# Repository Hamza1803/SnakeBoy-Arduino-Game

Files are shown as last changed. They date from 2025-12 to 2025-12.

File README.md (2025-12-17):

# 🐍 SnakeBoy – An Arduino-Powered Snake Game Console



A handheld, retro-inspired Snake game console built with Arduino and open-source hardware. SnakeBoy combines embedded programming, hardware optimization, and mechanical design into an accessible and highly optimized gaming device.

**Developed as part of the Creative Electronics course in the Electronics Engineering program at the University of Málaga.**

---

## 📋 Overview

SnakeBoy is a handheld console featuring the classic Snake game displayed on a 32×8 LED matrix. Built around an Arduino Leonardo-compatible board (Save Maker I), this project demonstrates practical embedded systems design with real-time gameplay, persistent high score storage, and optimized resource utilization.

### 🎯 Design Goals
- Demonstrate embedded programming and hardware optimization techniques
- Create a fully functional gaming device using accessible components
- Utilize open-source tools and methodologies
- Achieve minimal resource footprint (<15 KB Flash, ~2. 5 KB RAM)

---

## 🕹️ Key Features

- **Real-time Gameplay**:  Responsive joystick and directional button controls
- **Audio Feedback**: 6 distinct melodies via PWM buzzer
- **Persistent Storage**:  High scores saved in EEPROM memory
- **Efficient Architecture**: State-machine-driven game logic with zero blocking delays
- **Compact Footprint**: <15 KB Flash / ~2.5 KB RAM usage — highly optimized
- **Custom Graphics**: 7×5 pixel font and smooth menu animations
- **Custom Enclosure**: 3D-printed case with precision-engineered component cutouts
- **Status Indicator**: Visual feedback LED for game states
- **USB Powered**: Connected operation via 5V/1A USB power supply

---

## 📦 Hardware Specifications

### Core Components

| Component | Specification |
|---|---|
| **Microcontroller** | Save Maker I (Arduino Leonardo-compatible) |
| **Display** | 4× cascaded MAX7219 8×8 LED matrices (32×8 total resolution) |
| **Input:  Analog** | PS4-style analog joystick with integrated L3 push button |
| **Input: Digital** | 4× tactile push buttons (Up, Down, Left, Right) |
| **Audio Output** | Passive buzzer with PWM modulation |
| **Visual Indicator** | Red 5mm status LED |
| **Power Supply** | External 5V/1A USB power supply (wired connection) |

### Important Notes
⚠️ **LED Matrix Power**:  The LED matrix **must be powered externally via 5V** with a **shared ground connection** to prevent flickering and signal instability.

---

## 🔧 Pinout Configuration

| Component | Arduino Pin | Function |
|---|---|---|
| MAX7219 Data | D13 | Serial data input |
| MAX7219 Clock | D11 | Clock signal |
| MAX7219 Load | D10 | Latch/load signal |
| Buzzer | D12 | PWM audio output |
| Status LED | D7 | Visual state indicator |
| Joystick X-Axis | A0 | Analog X input |
| Joystick Y-Axis | A1 | Analog Y input |
| Joystick Button (L3) | D9 | Push button input |
| Up Button | D8 | Directional input |
| Down Button | D4 | Directional input |
| Left Button | D5 | Directional input |
| Right Button | D6 | Directional input |

**Note**: All digital buttons utilize the internal `INPUT_PULLUP` feature, eliminating the need for external pull-up resistors.

---

## 📁 Repository Structure

```
SnakeBoy-Arduino-Game/
├── arduino/
│   └── main/
│   │   ├── snake. cpp           # Main game logic and state machine
│   │   ├── display.cpp         # LED matrix driver and rendering
│   │   ├── inputs.cpp          # Joystick and button input handling
│   │   ├── sound.cpp           # Audio synthesis and melody management
│   │   ├── led. cpp             # Status LED control
│   │   └── config.h            # Hardware configuration and pin mappings
│   └── test/
│   │   └── test_display.txt
│   │   └── test_input.txt
│   │   └── test_led_buzzer.txt
├── 3D printer/
│   ├── case/               # OpenSCAD 3D models (parametric design)
│   │   ├── front_panel.scad
│   │   ├── back_panel.scad
│   │   └── button. scad
│   │   └── button. scad
│   │   └── button. scad
├── diagrams/           # Wiring and schematic diagrams
├── README.md               # This file
└── LICENSE                 # CC BY-NC-SA 4.0 License
```

---

## 🛠️ Getting Started

### Prerequisites
- Arduino IDE 1.8.0 or later
- Arduino Leonardo board or compatible (Save Maker I)
- MAX7219 LED matrix module (32×8)
- Joystick and push buttons
- Buzzer and status LED
- 5V/1A USB power supply

### Installation

1. **Clone the repository**
   ```bash
   git clone https://github.com/Hamza1803/SnakeBoy-Arduino-Game. git
   ```

2. **Install dependencies**
   - Download the `LedControl` library in Arduino IDE:  `Sketch → Include Library → Manage Libraries` → Search "LedControl"
   - Download the `MD_MAX72XX` library in Arduino IDE:  `Sketch → Include Library → Manage Libraries` → Search "MD_MAX72XX"

3. **Configure hardware**
   - Review `config.h` and verify pin mappings match your setup
   - Ensure external 5V power is connected to the LED matrix

4. **Upload firmware**
   - Connect your Arduino Leonardo board via USB
   - Open `snake.cpp` in Arduino IDE
   - Select Board: Arduino Leonardo
   - Click Upload

5. **Connect power**
   - Connect the 5V/1A USB power supply to the designated connector
   - The device should power on automatically

---

## 🎮 Gameplay Instructions

- **Move**: Use joystick or directional buttons (Up, Down, Left, Right)
- **Start Game**: Press any button or move joystick
- **Pause**: Press L3 button (joystick button)
- **Game Over**:  Collision with wall or self triggers game over
- **High Score**:  Automatically saved to EEPROM

---

## 👥 Contributors

**Project Team**:  
- **Hamza Lotfi** 
- **Andreea Simion** 

**Educational Institution**: 
Degree in Electronic Systems Engineering
University of Málaga, School of Telecommunications

---

## 📖 Additional Resources

- **Full Tutorial**: [SnakeBoy – An Arduino-Powered Snake Game Console](https://www.instructables.com/SnakeBoy-an-Arduino-Powered-Snake-Game-Console/) on Instructables
- **MAX7219 Datasheet**: Available from component suppliers
- **Video Full Game** : https://youtu.be/4og9s7oPVPE
---

## ⚖️ License

This project is licensed under the **Creative Commons Attribution-NonCommercial-ShareAlike 4.0 International (CC BY-NC-SA 4.0)** license.

**You are free to**:
- Share and adapt the material
- Use for educational purposes

**Under the terms that you**:
- Provide attribution to the original creators
- Do not use commercially
- Share derivative works under the same license

For complete license details, see the [LICENSE](./LICENSE) file or visit [creativecommons.org](https://creativecommons.org/licenses/by-nc-sa/4.0/).

---

## 🐛 Troubleshooting

### LED Matrix not displaying
- Verify external 5V power is connected with shared ground
- Check MAX7219 pin connections (DATA, CLK, LOAD)
- Test with the LedControl example sketch

### Joystick not responding
- Calibrate analog input in `inputs.cpp`
- Verify A0 and A1 connections
- Check for loose wiring

### Sound not working
- Verify buzzer polarity and D12 connection
- Check that `sound.cpp` is compiled

---

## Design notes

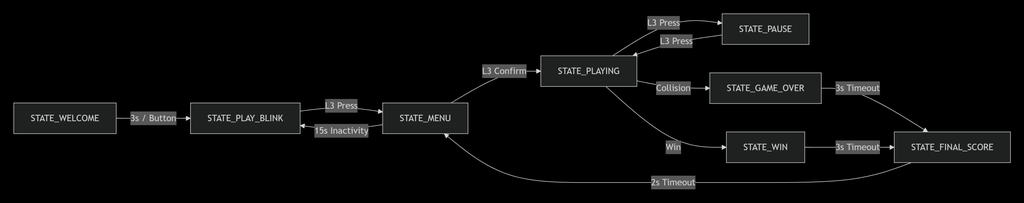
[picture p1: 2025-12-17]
diagrams.webp

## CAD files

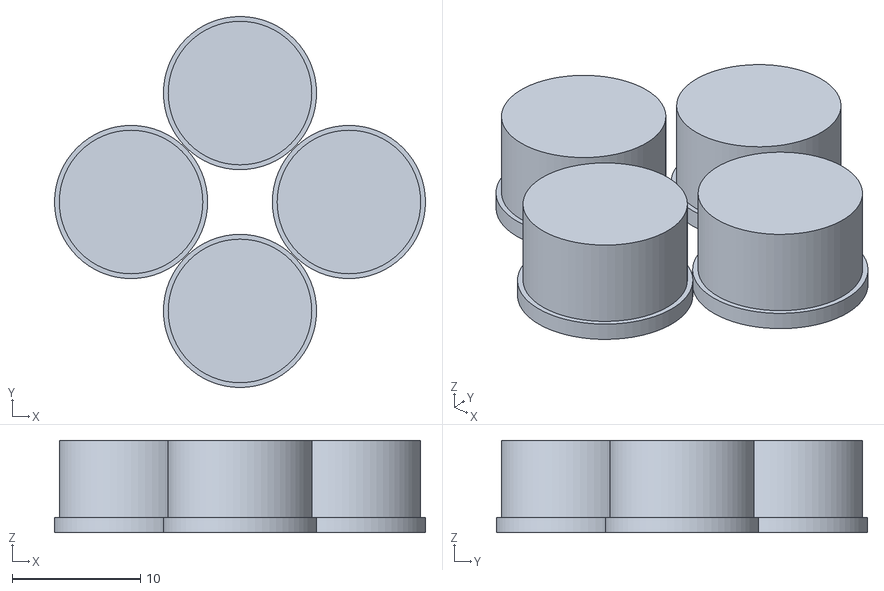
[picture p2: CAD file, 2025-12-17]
3d printer/button_v1.stl
28.9 x 28.9 x 7.20

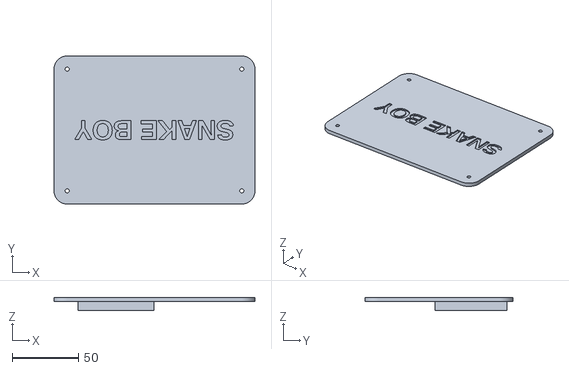
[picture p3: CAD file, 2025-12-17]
3d printer/back_v1.1.stl
152.0 x 112.0 x 10.0

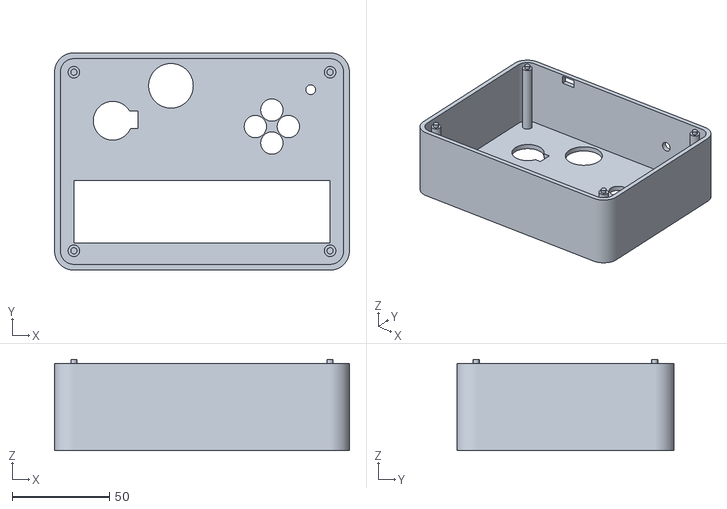
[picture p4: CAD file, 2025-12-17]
3d printer/front_v1.1.stl
152.0 x 112.0 x 47.0

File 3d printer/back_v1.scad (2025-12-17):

$fn = 64;

// General dimensions
box_length = 152;
box_width  = 112;
front_t = 3;
corner_r = 10;
screw_d = 3.15;
screw_offset = 10;

// Matrix window
matrix_w = 125;
matrix_h = 32;
matrix_y = 12;


// --------- ROUNDED BACK PLATE ----------
module back_plate() {
    hull(){
        for(x=[corner_r, box_length-corner_r])
            for(y=[corner_r, box_width-corner_r])
                translate([x, y, 0]) cylinder(h = front_t, r = corner_r);
    }
}


// -------- SAVEMAKER HOLDER --------
module savemaker_bottom_holder() {
    size = 54.6;
    wall = 1.8;
    height = 8;

    translate([5-2-60, -2, 0])
        cube([wall, size, height]);

    translate([size-60 - wall+6.15, -2, 0])  // .15 to tighten the Arduino
        cube([wall, size, height]);

    translate([3.6-60, -2, 0])
        cube([size+2, wall, height]);
}



// ================= FULL BACK PLATE ==================
union() {

    // --- TOP WITH CUTOUTS ---
    difference() {
        back_plate();

        // 4 screw holes
        for(x = [screw_offset, box_length - screw_offset])
            for(y = [screw_offset, box_width - screw_offset])
                translate([x, y, -1])
                    cylinder(h = front_t + 2, d = screw_d);

        // Text on the back
        translate([box_length/2, box_width/2,2])
            rotate([0,0,180])
            linear_extrude(height = 1.75)
                text("SNAKE BOY", size = 15, font = "Pricedown:style=Bold",
                     halign = "center", valign = "center");
    }


    // ===================
    //   3 X FOR MATRIX (FRONT SIDE)
    // ===================

    spacing = matrix_w / 3;

    

    // --- SAVEMAKER HOLDER ---
    translate([
        box_length/4 + 37,
        box_width - 57,
        front_t-10
    ])
        savemaker_bottom_holder();
}

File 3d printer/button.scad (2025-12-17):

// --------- XBOX A B X Y BUTTONS - STANDALONE (WITH RETENTION COLLAR) --------
// Designed to be printed separately or integrated into a panel
// Stay inside the box thanks to an internal collar

$fn = 64;

// === Adjustable parameters ===
btn_spacing = 8.5;    // distance between the center and each button
button_head_d = 11.20;    // diameter of the visible head (must be > btn_d)
retainer_d = 11.95;       // collar diameter (must be > btn_d, < space between buttons)
retainer_height = 1.2; // thin height of the collar (rests on the inside of the panel)
button_height = 6;     // total height of the visible head
stem_d = 6;            // stem diameter (for microswitch)
stem_height = 3;       // stem height
label_size = 4;
label_depth = 0.6;

// ------- Module: one button with collar and letter -------
module xbox_button(letter, dx, dy) {
    
    translate([dx, dy, retainer_height])
        cylinder(h = button_height, d = button_head_d);

    
    translate([dx, dy, 0])
        cylinder(h = retainer_height, d = retainer_d);

    
    translate([dx, dy, 0])
        cylinder(h = stem_height, d = stem_d);

    /
    translate([dx, dy, retainer_height + button_height - label_depth])
        linear_extrude(height = label_depth)
            text(letter, size = label_size, font = "Arial:style=Bold", halign="center", valign="center");
}

// Assembly of the 4 buttons 
union() {
    xbox_button("X", 0, -btn_spacing);   // Top
    xbox_button("A", 0, +btn_spacing);   // Bottom
    xbox_button("Y", -btn_spacing, 0);   // Left
    xbox_button("B", +btn_spacing, 0);   // Right
}

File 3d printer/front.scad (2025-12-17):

// --------- SNAKEBOY - FRONT PANEL v5 (with male studs) ---------

$fn = 64;

// General dimensions
box_length = 152;
box_width  = 112;
box_depth  = 33;
wall_t = 3;
front_t = 3;
corner_r = 10;

// Matrix MAX7219 window
matrix_w = 132.15;
matrix_h = 32.15; // .15 to leave some space for the matrix to fit in/out
matrix_y = 14;

// Joystick (KY-023)
joy_d = 20; // hole diameter
joy_x = 30;
joy_y = box_width - 35;

// Cross buttons (4 buttons)
btn_d = 11.5; // approximate real diameter
btn_spacing = 8.5; // spacing between centers
btn_center_x = box_length - 40;
btn_center_y = box_width - 38;

// Buzzer
buzzer_d = 22;
buzzer_x = joy_x+30;
buzzer_y = joy_y + 18;

// Indicator LED
led_d = 5;
led_x = btn_center_x+20;
led_y = btn_center_y + 26;

// Screws
screw_d = 3.0;
screw_offset = 10;

// Cable hole parameters
cable_d = 6;   // cable diameter
cable_x = box_length*3/4;   // centered in X
cable_y = box_width+1;      // near the front edge
cable_z = box_depth/2;    // centered in height

// USB hole parameters
// Mini-B USB hole parameters
usb_d = 6;   // cable diameter
usb_x = box_length/6 +8;  // left side +8 for exact Mini-B position
usb_y = box_width+1;     // centered in Y
usb_z = box_depth-1;     // near the bottom

// ------- Male stud module -------
module male_stud(x, y, stud_d, stud_h, hole_d) {
    // Stud body (cylinder protruding from the front face)
    translate([x, y, front_t])
        cylinder(h = stud_h, d = stud_d);

    // Central hole in the stud (for screwing from the back)
    translate([x, y, front_t - 1])
        cylinder(h = stud_h + 3, d = hole_d);
}

// ------- Rounded box shape -------
module rounded_box(l,w,h,r){
    hull(){
        for(x=[r,l-r])
            for(y=[r,w-r])
                translate([x,y,0]) cylinder(h=h, r=r);
    }
}

// ------- Main body construction -------
difference(){

    // Complete front enclosure
    rounded_box(box_length, box_width, box_depth, corner_r);

    // Hollow out the interior
    translate([wall_t,wall_t,front_t])
        rounded_box(box_length-2*wall_t, box_width-2*wall_t, box_depth, corner_r-wall_t);

    // Matrix MAX7219 window
    translate([(box_length-matrix_w)/2,
               matrix_y,
               -1])
        cube([matrix_w,matrix_h,front_t+4]);

    // Joystick hole
    translate([joy_x, joy_y, -1])
        cylinder(h=front_t+4, d=joy_d);

    // 4 cross buttons
    // Top button (△)
    translate([btn_center_x, btn_center_y - btn_spacing, -1])
        cylinder(h=front_t+4, d=btn_d);
    // Bottom button (X)
    translate([btn_center_x, btn_center_y + btn_spacing, -1])
        cylinder(h=front_t+4, d=btn_d);
    // Left button (□)
    translate([btn_center_x - btn_spacing, btn_center_y, -1])
        cylinder(h=front_t+4, d=btn_d);
    // Right button (◯)
    translate([btn_center_x + btn_spacing, btn_center_y, -1])
        cylinder(h=front_t+4, d=btn_d);

    // LED
    translate([led_x, led_y-7, -1])
        cylinder(h=front_t+4, d=led_d);

    // Buzzer (simple round hole)
    translate([buzzer_x, buzzer_y, -1])
        cylinder(h=front_t+4, d=buzzer_d);
        
    // Cable hole on the right side
    translate([cable_x, cable_y, cable_z])
    rotate([90,0,0])   // orient cylinder towards the front
    cylinder(h=wall_t+2, d=cable_d);
        
    // Rectangular hole for Mini-B USB
    translate([usb_x, usb_y, usb_z])
    rotate([90,90,0])   // orient cube horizontally
     cube([wall_t+2, 8, 5]);   //cylinder(h=wall_t+2, d=usb_d);

    // L3
    // Small rectangular hole to the right of the joystick (for L3 / clearance)
    translate([joy_x + 8, joy_y-4, -1])
    cube([front_t + 2, 9, 5]);  // [thickness, Y=9, X=5]
    
    //

}

// Male studs in the front face for screwing from the back

male_stud(x = screw_offset, y = screw_offset, stud_d = 6, stud_h = 30, hole_d = 3.2);

male_stud(x = box_length - screw_offset, y = screw_offset, stud_d = 6, stud_h = 30, hole_d = 3.2);

male_stud(x = screw_offset, y = box_width - screw_offset, stud_d = 6, stud_h = 30, hole_d = 3.2);

male_stud(x = box_length - screw_offset, y = box_width - screw_offset, stud_d = 6, stud_h = 30, hole_d = 3.2);

/*
// ------- Internal anti-flex reinforcement ribs -------
for(x=[30:30:(box_length-30)])
    translate([x, wall_t, front_t])
        cube([2,box_width-2*wall_t,6]);
*/

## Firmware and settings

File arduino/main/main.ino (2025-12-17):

#include <Arduino.h>
#include <EEPROM.h>
#include "snake.h"
#include "display.h"
#include "inputs.h"
#include "sound.h"
#include "led.h"
#include <avr/wdt.h>

// --- Game Constants ---
#define SNAKE_SPEED_EASY 400
#define SNAKE_SPEED_HARD 200

// --- SNAKE DATA ---
int16_t snakeX[MAX_SNAKE_LENGTH];
int16_t snakeY[MAX_SNAKE_LENGTH];
uint16_t snakeLength = 0;
uint8_t grid[ROWS][COLS];

int16_t dirX = 1, dirY = 0;
int16_t newDirX = 1, newDirY = 0;

int16_t foodX = 0, foodY = 0;
uint16_t score = 0;
bool isNewRecord = false;

// Scores - CHANGED to uint16_t
uint8_t bestScoreEasy = 0;
uint8_t bestScoreHard = 0;

// --- Game States ---
enum GameState {
  STATE_WELCOME,
  STATE_PLAY_BLINK,
  STATE_MENU,
  STATE_PLAYING,
  STATE_PAUSE,
  STATE_GAME_OVER_ANIMATION,
  STATE_WIN_ANIMATION,
  STATE_FINAL_SCORE
};

GameState state = STATE_WELCOME;

// --- Global Variables ---
bool l3PressedLast = false;
unsigned long lastMoveTime = 0;
bool soundPlayed = false;
bool welcomeAnimationStarted = false;

unsigned long l3PressStartTime = 0;
const unsigned long L3_HOLD_TIME = 2000;
uint8_t currentSelectedMode = 1;

// Game variables
bool wrapMode = true;
uint16_t currentGameSpeed = SNAKE_SPEED_EASY;

// Input buffering variables
int16_t bufferedDirX = 0, bufferedDirY = 0;
bool hasBufferedInput = false;

// Anti-freeze variables
unsigned long lastGameActivity = 0;
const unsigned long GAME_TIMEOUT = 3000; // 3 seconds max without movement

// Animation variables
unsigned long gameOverAnimationStart = 0;
unsigned long winAnimationStart = 0;
unsigned long scoreDisplayStart = 0;
bool animationCompleted = false;
bool soundTriggered = false;

// --- Soft reset ---
void softReset() {
  wdt_enable(WDTO_15MS);
  while (1);
}

// --- Reset ---
void resetGame() {
  // Reset all game variables
  snakeLength = 0;
  score = 0;
  
  // Call initialization functions
  initSnake(snakeX, snakeY, snakeLength, grid);
  generateFood(foodX, foodY, grid);
  
  dirX = newDirX = 1;
  dirY = newDirY = 0;
  
  soundPlayed = false;
  soundTriggered = false;
  lastMoveTime = millis();
  lastGameActivity = millis();
  
  setLEDState(LED_OFF_STATE);
  
  // Reset buffered inputs
  hasBufferedInput = false;
  bufferedDirX = 0;
  bufferedDirY = 0;
  
  // Update display
  updateDisplay(grid);
}

// --- Emergency check ---
void emergencyResetIfStuck() {
  static unsigned long lastEmergencyCheck = 0;
  static int stuckCounter = 0;
  
  if (millis() - lastEmergencyCheck > 500) { // Every 500ms
    lastEmergencyCheck = millis();
    
    // If playing for more than 2 seconds without movement
    if (state == STATE_PLAYING && (millis() - lastMoveTime > 2000)) {
      stuckCounter++;
      
      if (stuckCounter >= 3) { // Stuck for 1.5 seconds
        stuckCounter = 0;
        // Force a soft reset
        lastMoveTime = millis() - currentGameSpeed;
        
        // Check if the snake is initialized
        if (snakeLength == 0) {
          // Fully reset
          resetGame();
        }
      }
    } else {
      stuckCounter = 0; // Reset if everything is fine
    }
  }
}

// --- Setup ---
void setup() {
  //wdt_disable();
  initDisplay();
  initInputs();
  initSound();
  initLED();

  // Read best scores
  bestScoreEasy = EEPROM.read(0);
  bestScoreHard = EEPROM.read(1);

  noTone(BUZZER_PIN);
  digitalWrite(BUZZER_PIN, LOW);
  setLEDState(LED_SLOW_BLINK_STATE);
  state = STATE_WELCOME;
  welcomeAnimationStarted = false;
  
  // Random initialization
  randomSeed(analogRead(A2) + analogRead(A3));
}

// --- Main Loop ---
void loop() {
  InputState input = readInputs();
  bool l3PressedNow = input.l3Pressed;

  // Anti-freeze check
  emergencyResetIfStuck();

  // Handle long L3 press (power off/on)
  if (l3PressedNow && !l3PressedLast) {
    l3PressStartTime = millis();
  }
  if (!l3PressedNow && l3PressedLast) {
    l3PressStartTime = 0;
  }

  if (l3PressedNow && l3PressStartTime > 0 && (millis() - l3PressStartTime >= L3_HOLD_TIME)) {
    displayOffMessage();
    delay(3200);
    clearDisplay();
    tone(BUZZER_PIN, 262, 500);
    delay(500);
    noTone(BUZZER_PIN);
    setLEDState(LED_OFF_STATE);
    clearDisplay();

    while (digitalRead(JOYSTICK_L3_PIN) == LOW) delay(10);

    while (true) {
      input = readInputs();
      if (input.l3Pressed) {
        l3PressStartTime = millis();
        while (input.l3Pressed && (millis() - l3PressStartTime < L3_HOLD_TIME)) {
          input = readInputs();
          delay(10);
        }
        if (input.l3Pressed) {
          clearDisplay();
          displayOnMessage();
          delay(1200);
          clearDisplay();
          tone(BUZZER_PIN, 659, 300);
          delay(300);
          noTone(BUZZER_PIN);
          delay(100);
          softReset();
        }
      }
      delay(50);
    }
  }

  updateLEDPattern();

  // Short L3 click
  if (l3PressedNow && !l3PressedLast) {
    if (state == STATE_PLAYING) {
      state = STATE_PAUSE;
      displayPauseScreen();
      setLEDState(LED_FAST_BLINK_STATE);
    } else if (state == STATE_PAUSE) {
      state = STATE_PLAYING;
      clearDisplay();
      updateDisplay(grid);
      setLEDState(LED_OFF_STATE);
      lastMoveTime = millis(); // Reset timer
    } else if (state == STATE_MENU) {
      wrapMode = (currentSelectedMode == 1);
      currentGameSpeed = wrapMode ? SNAKE_SPEED_EASY : SNAKE_SPEED_HARD;
      state = STATE_PLAYING;
      resetGame();
      playStartSound();
      setLEDState(LED_OFF_STATE);
    } else if (state == STATE_PLAY_BLINK || state == STATE_WELCOME) {
      state = STATE_MENU;
      clearDisplay();
      displayModeSelectScreenWithSelection(currentSelectedMode);
      setLEDState(LED_ON_STATE);
    }
  }

  l3PressedLast = l3PressedNow;

  // State machine
  switch (state) {

    case STATE_WELCOME: {
      if (!welcomeAnimationStarted) {
        displayWelcomeScreen();
        playSnakeIntroTheme();
        welcomeAnimationStarted = true;
      }
      if (input.anyPressed && !input.l3Pressed) {
        state = STATE_MENU;
        clearDisplay();
        displayModeSelectScreenWithSelection(currentSelectedMode);
        setLEDState(LED_ON_STATE);
      } else {
        static unsigned long welcomeStartTime = 0;
        if (welcomeStartTime == 0) welcomeStartTime = millis();
        if (millis() - welcomeStartTime > 3000) {
          state = STATE_PLAY_BLINK;
          clearDisplay();
          displayPlayBlinkScreen();
          setLEDState(LED_SLOW_BLINK_STATE);
          welcomeStartTime = 0;
        }
      }
      break;
    }

    case STATE_PLAY_BLINK: {
      updatePlayBlink();
      if (input.anyPressed && !input.l3Pressed) {
        state = STATE_MENU;
        clearDisplay();
        displayModeSelectScreenWithSelection(currentSelectedMode);
        setLEDState(LED_ON_STATE);
      }
      break;
    }

    case STATE_MENU: {
      static unsigned long lastChange = 0;
      static unsigned long lastActivity = millis();
      if (input.anyPressed || input.dirX != 0 || input.dirY != 0) {
        lastActivity = millis();
      }
      if (millis() - lastActivity > 15000) {
        state = STATE_PLAY_BLINK;
        clearDisplay();
        displayPlayBlinkScreen();
        setLEDState(LED_SLOW_BLINK_STATE);
        lastActivity = millis();
        break;
      }
      if ((input.leftPressed || input.dirX == -1) && (millis() - lastChange > 200)) {
        currentSelectedMode = 1;
        lastChange = millis();
        displayModeSelectScreenWithSelection(currentSelectedMode);
        lastActivity = millis();
      }
      if ((input.rightPressed || input.dirX == 1) && (millis() - lastChange > 200)) {
        currentSelectedMode = 2;
        lastChange = millis();
        displayModeSelectScreenWithSelection(currentSelectedMode);
        lastActivity = millis();
      }
      updateModeSelectBlink();
      break;
    }

    case STATE_PLAYING: {
      // CRITICAL FIX: Always allow movement even without input
      bool shouldMove = (millis() - lastMoveTime >= currentGameSpeed);
      
      if (shouldMove) {
        lastMoveTime = millis();
        lastGameActivity = millis();

        // Input buffering
        if ((input.leftPressed || input.dirX == -1) && dirX == 0) {
          bufferedDirX = -1; bufferedDirY = 0;
          hasBufferedInput = true;
        }
        if ((input.rightPressed || input.dirX == 1) && dirX == 0) {
          bufferedDirX = 1; bufferedDirY = 0;
          hasBufferedInput = true;
        }
        if ((input.upPressed || input.dirY == -1) && dirY == 0) {
          bufferedDirX = 0; bufferedDirY = -1;
          hasBufferedInput = true;
        }
        if ((input.downPressed || input.dirY == 1) && dirY == 0) {
          bufferedDirX = 0; bufferedDirY = 1;
          hasBufferedInput = true;
        }

        // Apply buffered input if available
        if (hasBufferedInput) {
          newDirX = bufferedDirX;
          newDirY = bufferedDirY;
          dirX = newDirX;
          dirY = newDirY;
          hasBufferedInput = false;
        }

        uint16_t oldLength = snakeLength;
        
        // SAFETY CHECK: Ensure snake is valid
        if (snakeLength < 3 || snakeLength > MAX_SNAKE_LENGTH) {
          resetGame();
          break;
        }
        
        // Move snake
        moveSnake(snakeX, snakeY, snakeLength, oldLength, dirX, dirY, grid, wrapMode, foodX, foodY);
        
        // Check if food is eaten
        if (checkFood(snakeX, snakeY, snakeLength, foodX, foodY, grid)) {
          score++;
          playEatSound();
          setLEDState(LED_FAST_BLINK_STATE);
          delay(100);
          setLEDState(LED_OFF_STATE);

          // Update best scores
          if (wrapMode) {
            if (score > bestScoreEasy) {
              bestScoreEasy = score;
              EEPROM.update(0, bestScoreEasy);
            }
          } else {
            if (score > bestScoreHard) {
              bestScoreHard = score;
              EEPROM.update(1, bestScoreHard);
            }
          }
        }

        // Check collisions
        if (checkCollision(snakeX, snakeY, snakeLength, !wrapMode)) {
          setLEDState(LED_ON_STATE);
          state = STATE_GAME_OVER_ANIMATION;
          gameOverAnimationStart = millis();
          soundTriggered = false;
          break;
        }

        // Check win
        if (checkWin(snakeLength)) {
          setLEDState(LED_VICTORY_STATE);
          state = STATE_WIN_ANIMATION;
          winAnimationStart = millis();
          soundTriggered = false;
          break;
        }

        // Update display
        updateDisplay(grid);
      }
      
      // Global timeout check
      if (millis() - lastGameActivity > GAME_TIMEOUT) {
        state = STATE_MENU;
        clearDisplay();
        displayModeSelectScreenWithSelection(currentSelectedMode);
        setLEDState(LED_ON_STATE);
      }
      
      break;
    }

    case STATE_PAUSE:
      // Do nothing, wait for input
      break;

    case STATE_GAME_OVER_ANIMATION: {
      // Play sound ONLY ONCE
      if (!soundTriggered) {
        playLoseSound();
        soundTriggered = true;
      }
      
      // Display blinking LOST for 3 seconds
      displayLostAnimation(wrapMode ? bestScoreEasy : bestScoreHard);
      
      if (millis() - gameOverAnimationStart > 3000) {
        state = STATE_FINAL_SCORE;
        scoreDisplayStart = millis();
        animationCompleted = false;
      }
      break;
    }

    case STATE_WIN_ANIMATION: {
      // Play sound ONLY ONCE
      if (!soundTriggered) {
        if (wrapMode) playWinSound(); else playHardWinSound();
        soundTriggered = true;
      }
      
      // Display blinking WIN for 3 seconds
      displayWinAnimation(wrapMode ? bestScoreEasy : bestScoreHard);
      
      if (millis() - winAnimationStart > 3000) {
        state = STATE_FINAL_SCORE;
        scoreDisplayStart = millis();
        animationCompleted = false;
      }
      break;
    }

    case STATE_FINAL_SCORE: {
      // Display final score with star if record
      if (!animationCompleted) {
        bool isNewRecord = false;
        if (wrapMode) {
          isNewRecord = (score >= bestScoreEasy);
        } else {
          isNewRecord = (score >= bestScoreHard);
        }
        displayFinalScore(score, wrapMode ? bestScoreEasy : bestScoreHard, isNewRecord);
        animationCompleted = true;
      }
      
      // Stay on this screen for 2 seconds
      if (millis() - scoreDisplayStart > 2000) {
        state = STATE_MENU;
        clearDisplay();
        displayModeSelectScreenWithSelection(currentSelectedMode);
        setLEDState(LED_ON_STATE);
        
        // Reset variables
        soundPlayed = false;
        soundTriggered = false;
        animationCompleted = false;
        gameOverAnimationStart = 0;
        winAnimationStart = 0;
        scoreDisplayStart = 0;
      }
      break;
    }
  }

  delay(10);
}

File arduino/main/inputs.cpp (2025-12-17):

#include "inputs.h"

// Debounce and filtering

// Variables for filtering
static int lastFilteredX = JOYSTICK_HOME_X;
static int lastFilteredY = JOYSTICK_HOME_Y;
static bool lastL3State = HIGH;
static unsigned long lastL3Debounce = 0;

void initInputs() {
  pinMode(JOYSTICK_X_PIN, INPUT);
  pinMode(JOYSTICK_Y_PIN, INPUT);
  pinMode(JOYSTICK_L3_PIN, INPUT_PULLUP);

  pinMode(BTN_UP_PIN, INPUT_PULLUP);
  pinMode(BTN_DOWN_PIN, INPUT_PULLUP);
  pinMode(BTN_LEFT_PIN, INPUT_PULLUP);
  pinMode(BTN_RIGHT_PIN, INPUT_PULLUP);

  // Initial reading
  analogRead(JOYSTICK_X_PIN);
  analogRead(JOYSTICK_Y_PIN);
  
  // Initialize states
  lastL3State = digitalRead(JOYSTICK_L3_PIN);
}

InputState readInputs() {
  InputState state = {0};

  // Joystick reading and filtering
  int rawX = analogRead(JOYSTICK_X_PIN);
  int rawY = analogRead(JOYSTICK_Y_PIN);
  
  // Simple low-pass filter (reduces noise)
  int filteredX = (rawX + lastFilteredX) / 2;
  int filteredY = (rawY + lastFilteredY) / 2;
  lastFilteredX = filteredX;
  lastFilteredY = filteredY;

  // Convert to directions
  state.dirX = getDirectionFromAnalog(filteredX, JOYSTICK_HOME_X, JOYSTICK_THRESHOLD);
  state.dirY = getDirectionFromAnalog(filteredY, JOYSTICK_HOME_Y, JOYSTICK_THRESHOLD);

  // Debounced reading of L3 button
  bool currentL3State = digitalRead(JOYSTICK_L3_PIN);
  unsigned long currentTime = millis();
  
  if (currentL3State != lastL3State) {
    lastL3Debounce = currentTime;
  }
  
  if ((currentTime - lastL3Debounce) > DEBOUNCE_DELAY) {
    state.l3Pressed = (currentL3State == LOW);
  }
  
  lastL3State = currentL3State;

  // Button reading
  state.upPressed = (digitalRead(BTN_UP_PIN) == LOW);
  state.downPressed = (digitalRead(BTN_DOWN_PIN) == LOW);
  state.leftPressed = (digitalRead(BTN_LEFT_PIN) == LOW);
  state.rightPressed = (digitalRead(BTN_RIGHT_PIN) == LOW);

  // Determine if any input is active
  state.anyPressed = (state.dirX != 0 || state.dirY != 0 ||
                      state.l3Pressed ||
                      state.upPressed || state.downPressed || 
                      state.leftPressed || state.rightPressed);

  return state;
}

int8_t getDirectionFromAnalog(int analogValue, int homeValue, int threshold) {
  int difference = analogValue - homeValue;
  
  // Dead zone
  if (abs(difference) < JOYSTICK_DEADZONE) {
    return 0;
  }
  
  // Direction thresholds
  if (difference < -threshold) {
    return -1; // Left or Up
  }
  else if (difference > threshold) {
    return 1;  // Right or Down
  }
  
  return 0;  // Intermediate zone
}
